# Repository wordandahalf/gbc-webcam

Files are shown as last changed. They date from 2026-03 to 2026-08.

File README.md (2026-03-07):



### gbc-webcam
A color webcam made using the M64282FP silicon retina found in the Gameboy Camera. Using a trichroic prism salvaged from a Hitachi HV-C20 3CCD camera, three M64282FP sensors are combined with an STM32H755 Nucleo development board to create a fully functional USB webcam.

##### Structure
- `adapters/` contains the FreeCAD files for the shims to adapt the prism mounting system to the sensors.
- `analysis/` contains Typst source files to generate a report regarding the analysis of the silicon retnia.
- `calibration/` contains Python source files to perform the necessary color calibration of the three sensors.
- `firmware/` contains the STM32CubeIDE project for programming the STM32H755 development board with the USB webcam firmware.

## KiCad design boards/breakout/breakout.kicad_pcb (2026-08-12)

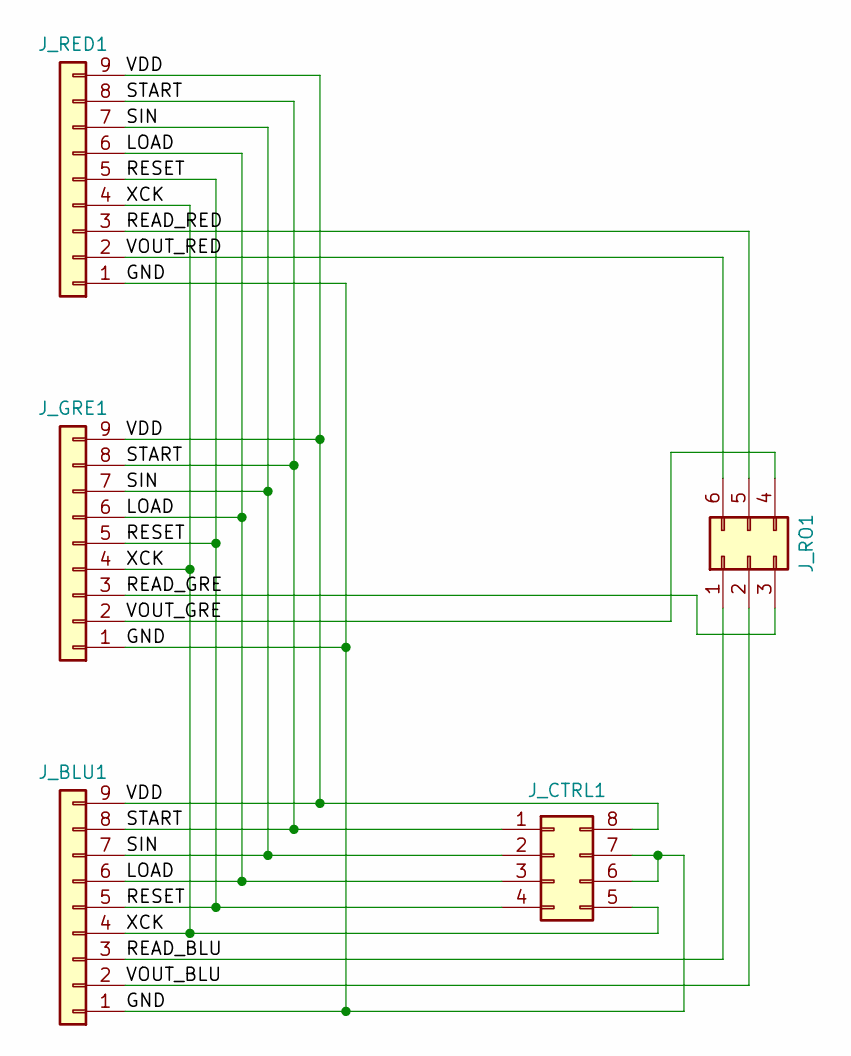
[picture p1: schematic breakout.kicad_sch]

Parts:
J_BLU1: Conn_01x09; JST_ZH_B9B-ZR_1x09_P1.50mm_Vertical
J_CTRL1: Conn_02x04_Counter_Clockwise; PinSocket_2x04_P2.54mm_Horizontal
J_GRE1: Conn_01x09; JST_ZH_B9B-ZR_1x09_P1.50mm_Vertical
J_RED1: Conn_01x09; JST_ZH_B9B-ZR_1x09_P1.50mm_Vertical
J_RO1: Conn_02x03_Counter_Clockwise; PinSocket_2x03_P2.54mm_Horizontal

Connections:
/GND: J_BLU1.1, J_CTRL1.6, J_CTRL1.7, J_GRE1.1, J_RED1.1
/LOAD: J_BLU1.6, J_CTRL1.3, J_GRE1.6, J_RED1.6
/READ_BLU: J_BLU1.3, J_RO1.1
/READ_GRE: J_GRE1.3, J_RO1.3
/READ_RED: J_RED1.3, J_RO1.5
/RESET: J_BLU1.5, J_CTRL1.4, J_GRE1.5, J_RED1.5
/SIN: J_BLU1.7, J_CTRL1.2, J_GRE1.7, J_RED1.7
/START: J_BLU1.8, J_CTRL1.1, J_GRE1.8, J_RED1.8
/VDD: J_BLU1.9, J_CTRL1.8, J_GRE1.9, J_RED1.9
/VOUT_BLU: J_BLU1.2, J_RO1.2
/VOUT_GRE: J_GRE1.2, J_RO1.4
/VOUT_RED: J_RED1.2, J_RO1.6
/XCK: J_BLU1.4, J_CTRL1.5, J_GRE1.4, J_RED1.4

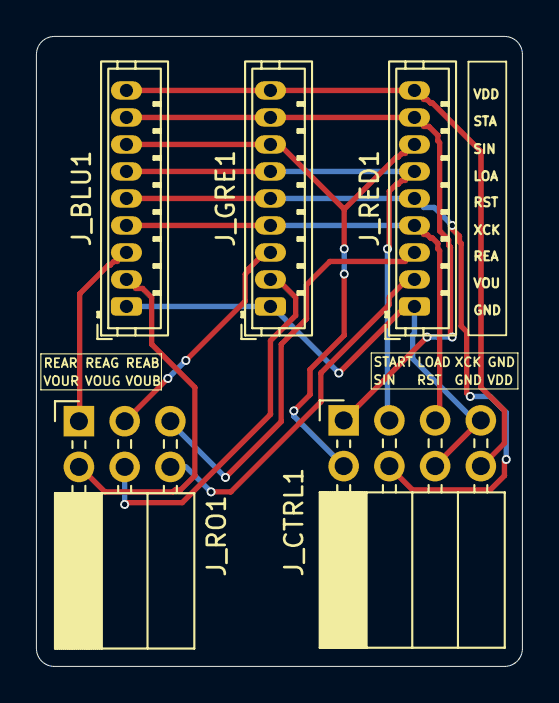
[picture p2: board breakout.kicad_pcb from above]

Board: 2 copper layers, 27.0 x 35.0 mm, 5 parts (0 on the bottom side), 13 nets.

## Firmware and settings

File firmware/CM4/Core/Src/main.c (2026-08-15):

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
/* Includes ------------------------------------------------------------------*/
#include "main.h"

/* USER CODE BEGIN Includes */
#include "m64282fp.h"
#include "stm32h7xx_hal_adc_ex.h"
#include "stm32h7xx_nucleo.h"
/* USER CODE END Includes */

/* USER CODE BEGIN PD */

/* DUAL_CORE_BOOT_SYNC_SEQUENCE: Define for dual core boot synchronization    */
/*                             demonstration code based on hardware semaphore */
/* This define is present in both CM7/CM4 projects                            */
/* To comment when developing/debugging on a single core                     */
// #define DUAL_CORE_BOOT_SYNC_SEQUENCE

#if defined(DUAL_CORE_BOOT_SYNC_SEQUENCE)
#ifndef HSEM_ID_0
#define HSEM_ID_0 (0U) /* HW semaphore 0*/
#endif
#endif /* DUAL_CORE_BOOT_SYNC_SEQUENCE */

/* USER CODE END PD */


COM_InitTypeDef BspCOMInit;
__IO uint32_t BspButtonState = BUTTON_RELEASED;
ADC_HandleTypeDef hadc1;
DMA_HandleTypeDef hdma_adc1;

TIM_HandleTypeDef htim2;
DMA_HandleTypeDef hdma_tim2_up;

static void MX_GPIO_Init(void);
static void MX_TIM2_Init(void);
static void MX_ADC1_Init(void);
/* USER CODE BEGIN 0 */
uint32_t m64282fp_serial_config_stream[91 + 1];

void m64282fp_reset(m64282fp_registers_t *registers, bool skip_reconfigure) {
  m64282fp_pack_bsrr(registers, m64282fp_serial_config_stream, skip_reconfigure);

  TIM2->DIER |= TIM_DIER_UDE;
  HAL_DMA_Start(&hdma_tim2_up, (uint32_t) m64282fp_serial_config_stream, (uint32_t) &GPIOE->BSRR, sizeof(m64282fp_serial_config_stream) / sizeof(uint32_t));
  HAL_TIM_PWM_Start(&htim2, TIM_CHANNEL_1);
  HAL_TIM_Base_Start(&htim2);
}

__attribute__((section("non_cacheable_area"), aligned(8)))
static uint16_t adc_buffer[128*128 + 2];

static volatile bool should_write_data = false;

void HAL_ADC_ConvHalfCpltCallback(ADC_HandleTypeDef *hadc) {}

void HAL_ADC_ConvCpltCallback(ADC_HandleTypeDef *hadc) {
	should_write_data = true;
    BSP_LED_Toggle(LED_YELLOW);
}

void HAL_GPIO_EXTI_Callback(uint16_t GPIO_Pin)
{
  switch (GPIO_Pin) {
    case PIN_READ_BLUE:
      if (HAL_ADC_Start_DMA(&hadc1, (uint32_t*) adc_buffer, 128 * 128) != HAL_OK) {
        Error_Handler();
      }
      BSP_LED_Toggle(LED_GREEN);
      break;
    default:
      break;
  }
}

/* USER CODE END 0 */

/**
  * @brief  The application entry point.
  * @retval int
  */
int main(void)
{

  /* USER CODE BEGIN 1 */
  // PC0 - ADC1_INP10, PC1 - ADC2_INP11, PC2_C - ADC3_INP0
  /* USER CODE END 1 */

/* USER CODE BEGIN Boot_Mode_Sequence_1 */
#if defined(DUAL_CORE_BOOT_SYNC_SEQUENCE)
  /*HW semaphore Clock enable*/
  __HAL_RCC_HSEM_CLK_ENABLE();
  /* Activate HSEM notification for Cortex-M4*/
  HAL_HSEM_ActivateNotification(__HAL_HSEM_SEMID_TO_MASK(HSEM_ID_0));
  /*
  Domain D2 goes to STOP mode (Cortex-M4 in deep-sleep) waiting for Cortex-M7 to
  perform system initialization (system clock config, external memory configuration.. )
  */
  HAL_PWREx_ClearPendingEvent();
  HAL_PWREx_EnterSTOPMode(PWR_MAINREGULATOR_ON, PWR_STOPENTRY_WFE, PWR_D2_DOMAIN);
  /* Clear HSEM flag */
  __HAL_HSEM_CLEAR_FLAG(__HAL_HSEM_SEMID_TO_MASK(HSEM_ID_0));

#endif /* DUAL_CORE_BOOT_SYNC_SEQUENCE */
/* USER CODE END Boot_Mode_Sequence_1 */
  /* MCU Configuration--------------------------------------------------------*/

  /* Reset of all peripherals, Initializes the Flash interface and the Systick. */
  HAL_Init();

  /* USER CODE BEGIN SysInit */
  MX_DMA_Init();
  /* USER CODE END SysInit */

  /* Initialize all configured peripherals */
  MX_GPIO_Init();
  MX_TIM2_Init();
  MX_ADC1_Init();
  /* USER CODE BEGIN 2 */
  // calibrate adc
  ADC1->CR &= ~ADC_CR_ADEN;
  ADC1->CR |= ADC_CR_ADCALLIN;
  ADC1->CR |= ADC_CR_ADCAL;
  while((ADC1->CR & ADC_CR_ADCAL) != 0);

  // reset camera
  m64282fp_reset(&m64282fp_default_registers, false);
  /* USER CODE END 2 */

  /* Initialize leds */
  BSP_LED_Init(LED_GREEN);
  BSP_LED_Init(LED_YELLOW);
  BSP_LED_Init(LED_RED);

  /* Initialize USER push-button, will be used to trigger an interrupt each time it's pressed.*/
  BSP_PB_Init(BUTTON_USER, BUTTON_MODE_EXTI);

  /* Initialize COM1 port (115200, 8 bits (7-bit data + 1 stop bit), no parity */
  BspCOMInit.BaudRate   = 115200;
  BspCOMInit.WordLength = COM_WORDLENGTH_8B;
  BspCOMInit.StopBits   = COM_STOPBITS_1;
  BspCOMInit.Parity     = COM_PARITY_NONE;
  BspCOMInit.HwFlowCtl  = COM_HWCONTROL_NONE;
  if (BSP_COM_Init(COM1, &BspCOMInit) != BSP_ERROR_NONE)
  {
    Error_Handler();
  }

  /* USER CODE BEGIN BSP */
  BSP_LED_Off(LED_GREEN);
  BSP_LED_Off(LED_YELLOW);
  BSP_LED_Off(LED_RED);
  /* USER CODE END BSP */

  /* Infinite loop */
  /* USER CODE BEGIN WHILE */
  while (1)
  {
    /* USER CODE END WHILE */

    /* USER CODE BEGIN 3 */
  }
  /* USER CODE END 3 */
}

/**
  * @brief ADC1 Initialization Function
  * @param None
  * @retval None
  */
static void MX_ADC1_Init(void)
{

  ADC_MultiModeTypeDef multimode = {0};
  ADC_ChannelConfTypeDef sConfig = {0};

  /** Common config
  */
  hadc1.Instance = ADC1;
  hadc1.Init.ClockPrescaler = ADC_CLOCK_ASYNC_DIV2;
  hadc1.Init.Resolution = ADC_RESOLUTION_16B;
  hadc1.Init.ScanConvMode = ADC_SCAN_DISABLE;
  hadc1.Init.EOCSelection = ADC_EOC_SINGLE_CONV;
  hadc1.Init.LowPowerAutoWait = DISABLE;
  hadc1.Init.ContinuousConvMode = DISABLE;
  hadc1.Init.NbrOfConversion = 1;
  hadc1.Init.DiscontinuousConvMode = DISABLE;
  hadc1.Init.ExternalTrigConv = ADC_EXTERNALTRIG_T2_TRGO;
  hadc1.Init.ExternalTrigConvEdge = ADC_EXTERNALTRIGCONVEDGE_RISING;
  hadc1.Init.ConversionDataManagement = ADC_CONVERSIONDATA_DMA_ONESHOT;
  hadc1.Init.Overrun = ADC_OVR_DATA_PRESERVED;
  hadc1.Init.LeftBitShift = ADC_LEFTBITSHIFT_NONE;
  hadc1.Init.OversamplingMode = DISABLE;
  hadc1.Init.Oversampling.Ratio = 1;
  if (HAL_ADC_Init(&hadc1) != HAL_OK)
  {
    Error_Handler();
  }

  /** Configure the ADC multi-mode
  */
  multimode.Mode = ADC_MODE_INDEPENDENT;
  if (HAL_ADCEx_MultiModeConfigChannel(&hadc1, &multimode) != HAL_OK)
  {
    Error_Handler();
  }

  /** Configure Regular Channel
  */
  sConfig.Channel = ADC_CHANNEL_10;
  sConfig.Rank = ADC_REGULAR_RANK_1;
  sConfig.SamplingTime = ADC_SAMPLETIME_1CYCLE_5;
  sConfig.SingleDiff = ADC_SINGLE_ENDED;
  sConfig.OffsetNumber = ADC_OFFSET_NONE;
  sConfig.Offset = 0;
  sConfig.OffsetSignedSaturation = DISABLE;
  if (HAL_ADC_ConfigChannel(&hadc1, &sConfig) != HAL_OK)
  {
    Error_Handler();
  }
}

/**
  * @brief TIM2 Initialization Function
  * @param None
  * @retval None
  */
static void MX_TIM2_Init(void)
{

  TIM_ClockConfigTypeDef sClockSourceConfig = {0};
  TIM_MasterConfigTypeDef sMasterConfig = {0};
  TIM_OC_InitTypeDef sConfigOC = {0};

  htim2.Instance = TIM2;
  htim2.Init.Prescaler = 15;
  htim2.Init.CounterMode = TIM_COUNTERMODE_UP;
  htim2.Init.Period = 7;
  htim2.Init.ClockDivision = TIM_CLOCKDIVISION_DIV1;
  htim2.Init.AutoReloadPreload = TIM_AUTORELOAD_PRELOAD_DISABLE;
  if (HAL_TIM_Base_Init(&htim2) != HAL_OK)
  {
    Error_Handler();
  }
  sClockSourceConfig.ClockSource = TIM_CLOCKSOURCE_INTERNAL;
  if (HAL_TIM_ConfigClockSource(&htim2, &sClockSourceConfig) != HAL_OK)
  {
    Error_Handler();
  }
  if (HAL_TIM_PWM_Init(&htim2) != HAL_OK)
  {
    Error_Handler();
  }
  sMasterConfig.MasterOutputTrigger = TIM_TRGO_UPDATE;
  sMasterConfig.MasterSlaveMode = TIM_MASTERSLAVEMODE_DISABLE;
  if (HAL_TIMEx_MasterConfigSynchronization(&htim2, &sMasterConfig) != HAL_OK)
  {
    Error_Handler();
  }
  sConfigOC.OCMode = TIM_OCMODE_PWM1;
  sConfigOC.Pulse = 4;
  sConfigOC.OCPolarity = TIM_OCPOLARITY_LOW;
  sConfigOC.OCFastMode = TIM_OCFAST_DISABLE;
  if (HAL_TIM_PWM_ConfigChannel(&htim2, &sConfigOC, TIM_CHANNEL_1) != HAL_OK)
  {
    Error_Handler();
  }
  HAL_TIM_MspPostInit(&htim2);

}

/**
  * Enable DMA controller clock
  */
void MX_DMA_Init(void)
{

  /* DMA controller clock enable */
  __HAL_RCC_DMA1_CLK_ENABLE();

  /* DMA interrupt init */
  /* DMA1_Stream0_IRQn interrupt configuration */
  HAL_NVIC_SetPriority(DMA1_Stream0_IRQn, 0, 0);
  HAL_NVIC_EnableIRQ(DMA1_Stream0_IRQn);
  /* DMA1_Stream1_IRQn interrupt configuration */
  HAL_NVIC_SetPriority(DMA1_Stream1_IRQn, 0, 0);
  HAL_NVIC_EnableIRQ(DMA1_Stream1_IRQn);

}

/**
  * @brief GPIO Initialization Function
  * @param None
  * @retval None
  */
static void MX_GPIO_Init(void)
{
  GPIO_InitTypeDef GPIO_InitStruct = {0};
  /* GPIO Ports Clock Enable */
  __HAL_RCC_GPIOC_CLK_ENABLE();
  __HAL_RCC_GPIOE_CLK_ENABLE();
  __HAL_RCC_GPIOA_CLK_ENABLE();

  /*Configure GPIO pin Output Level */
  HAL_GPIO_WritePin(GPIOE, GPIO_PIN_9|GPIO_PIN_10|GPIO_PIN_11|GPIO_PIN_12, GPIO_PIN_RESET);

  /*Configure GPIO pin : PE8 */
  GPIO_InitStruct.Pin = GPIO_PIN_8;
  GPIO_InitStruct.Mode = GPIO_MODE_IT_RISING;
  GPIO_InitStruct.Pull = GPIO_PULLDOWN;
  HAL_GPIO_Init(GPIOE, &GPIO_InitStruct);

  /*Configure GPIO pins : PE9 PE10 PE11 PE12 */
  GPIO_InitStruct.Pin = GPIO_PIN_9|GPIO_PIN_10|GPIO_PIN_11|GPIO_PIN_12;
  GPIO_InitStruct.Mode = GPIO_MODE_OUTPUT_PP;
  GPIO_InitStruct.Pull = GPIO_NOPULL;
  GPIO_InitStruct.Speed = GPIO_SPEED_FREQ_LOW;
  HAL_GPIO_Init(GPIOE, &GPIO_InitStruct);

  /*Configure GPIO pins : PA8 PA11 PA12 */
  GPIO_InitStruct.Pin = GPIO_PIN_8|GPIO_PIN_11|GPIO_PIN_12;
  GPIO_InitStruct.Mode = GPIO_MODE_AF_PP;
  GPIO_InitStruct.Pull = GPIO_NOPULL;
  GPIO_InitStruct.Speed = GPIO_SPEED_FREQ_LOW;
  GPIO_InitStruct.Alternate = GPIO_AF10_OTG1_FS;
  HAL_GPIO_Init(GPIOA, &GPIO_InitStruct);

  /* EXTI interrupt init*/
  HAL_NVIC_SetPriority(EXTI9_5_IRQn, 0, 0);
  HAL_NVIC_EnableIRQ(EXTI9_5_IRQn);

}

/**
  * @brief  BSP Push Button callback
  * @param  Button Specifies the pressed button
  * @retval None
  */
void BSP_PB_Callback(Button_TypeDef Button)
{
  if (Button == BUTTON_USER)
  {
    BspButtonState = BUTTON_PRESSED;
  }
}

/**
  * @brief  This function is executed in case of error occurrence.
  * @retval None
  */
void Error_Handler(void)
{
  /* USER CODE BEGIN Error_Handler_Debug */
  /* User can add his own implementation to report the HAL error return state */
  __disable_irq();

  BSP_LED_Off(LED_RED);
  BSP_LED_Off(LED_YELLOW);
  BSP_LED_Off(LED_GREEN);
  while (1)
  {
	  BSP_LED_Toggle(LED_RED);
	  BSP_LED_Toggle(LED_YELLOW);
	  BSP_LED_Toggle(LED_GREEN);
	  HAL_Delay(500);
  }
  /* USER CODE END Error_Handler_Debug */
}
#ifdef USE_FULL_ASSERT
/**
  * @brief  Reports the name of the source file and the source line number
  *         where the assert_param error has occurred.
  * @param  file: pointer to the source file name
  * @param  line: assert_param error line source number
  * @retval None
  */
void assert_failed(uint8_t *file, uint32_t line)
{
  /* USER CODE BEGIN 6 */
  /* User can add his own implementation to report the file name and line number,
     ex: printf("Wrong parameters value: file %s on line %d\r\n", file, line) */
  /* USER CODE END 6 */
}
#endif /* USE_FULL_ASSERT */

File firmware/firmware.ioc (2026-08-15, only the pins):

Mcu.UserName=STM32H755ZITx
PA11.Signal=USB_OTG_FS_DM
PA12.Signal=USB_OTG_FS_DP
PA8.Signal=USB_OTG_FS_SOF
PA9.Signal=USB_OTG_FS_VBUS
PC0.Signal=ADCx_INP10
PD10.GPIO_Label=USB_OTG_FS_PWR_EN
PD10.Signal=GPIO_Output
PD8.Signal=USART3_TX
PD9.Signal=USART3_RX
PE10.Signal=GPIO_Output
PE11.Signal=GPIO_Output
PE12.Signal=GPIO_Output
PE8.Signal=GPXTI8
PE9.Signal=GPIO_Output
PG7.GPIO_Label=USB_OTG_FS_OVCR
PG7.Signal=GPXTI7

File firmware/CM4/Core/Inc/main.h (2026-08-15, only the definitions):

#define PIN_GPIO_BANK GPIOE
#define PIN_READ_BLUE GPIO_PIN_8
#define PIN_START GPIO_PIN_9
#define PIN_LOAD GPIO_PIN_10
#define PIN_RESET GPIO_PIN_11
#define PIN_SIN GPIO_PIN_12

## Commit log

2026-03-07 add: new STM32-based implmenetation
2026-08-12 add: v1 of breakout PCB
    [breakout.kicad_pcb, breakout.kicad_sch]
2026-08-12 add: stm32h755 SVDs for portable building
2026-08-12 add: initial port, still need ADC configuration
2026-08-15 change: migrate project from VSCode, add ADC DMA and transfer

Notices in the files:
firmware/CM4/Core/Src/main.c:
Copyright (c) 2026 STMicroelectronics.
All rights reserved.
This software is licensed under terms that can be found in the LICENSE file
